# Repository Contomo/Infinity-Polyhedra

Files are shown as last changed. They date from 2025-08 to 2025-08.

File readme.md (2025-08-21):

# Infinity Polyhedra

This repository contains the files, notes, and software related to building an infinity dodecahedron. The project is built around an STM32F401 microcontroller and a custom Python desktop application. While designed for a dodecahedron, the core logic is intended to be flexible enough for other polyhedral geometries.

> *This is a personal project and a work-in-progress.*

<p align="center">
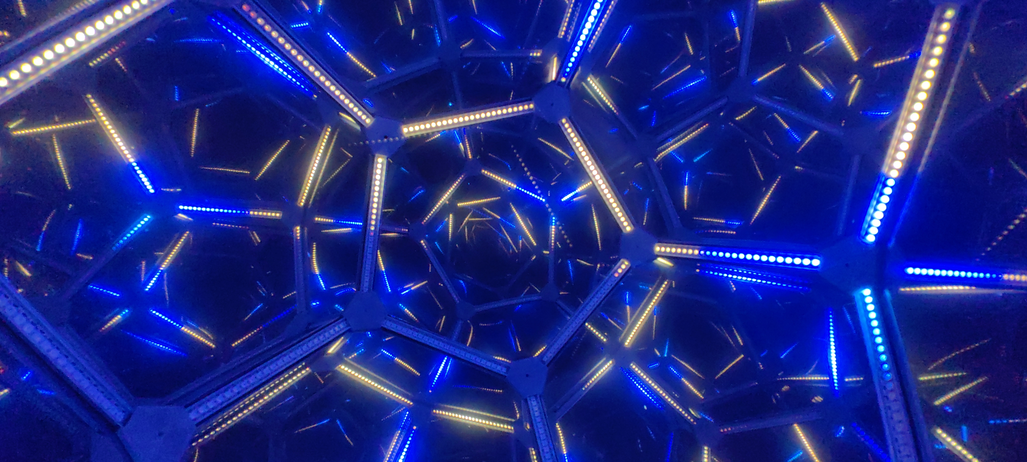
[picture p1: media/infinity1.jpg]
abyss
  
</p>

> [!NOTE]
> This is a complex project that requires some familiarity with Python and STM32CubeIDE. Unless you are simply replicating the build process with the same components, this will likely not be a "download and run" solution.

## Table of Contents

*   [Features](#features)
*   [Hardware](#hardware)
*   [Software](#software)
*   [Design Files](#design-files)
*   [Technical Notes & How It Works](#technical-notes--how-it-works)

## Features

*   **High-Framerate Animations:** The firmware uses a multi-SPI DMA approach to drive a large number of LEDs smoothly, achieving highframe rates.
*   **Geometry-Aware Logic:** The firmware includes a geometric core that can, in theory, be adapted for various polyhedra.
*   **Interactive Edge Remapping:** The app provides a debug mode for remapping physical LED strips to their correct logical edges on the 3D model. This allows for 'vibe wirering'.
*   **PS4 Controller Interface:** The desktop app is built around the use of a PS4 controller, which is the primary method for sending commands to the microcontroller to switch animation modes and operate the remapping interface.

## Hardware

This section covers the physical build of the dodecahedron, including the electronics, materials, and construction notes from my experience.

![PLACEHOLDER: Photo of the fully assembled and lit dodecahedron]

### Electronics

*   **Microcontroller:** STM32F401.
*   **LED Strips:** WS2812B-style addressable LEDs. High-density strips (e.g., 144/m) are recommended. *(1515 300/m are of course better if your pockets allow it)*
*   **Power:** `TODO: HOW MANY PIXIES`

`TODO: Wirering, .4mm enameled and regular corner wired`

### Frame and Panels

*   **Frame:** The dodecahedron frame is built from LED extrusions. (15mm x 10mm)
*   **Panels:** 4mm acrylic panels. i recommend some 3mm foam tape to light seal the edges.
*   **Mirror Film:** The infinity effect is created with one-way mirror foil. The cheapest foil from AliExpress was surprisingly effective, but higher quality film is recommended.
    > **Note on Brightness:** The LEDs can be overwhelmingly bright. Consider using a mirror film/tint 90%+ (e.g., stacking two layers of 80% film) to trade in brightness for reflections.

### Stand

The stand is built from fairly regular aluminum extrusions. (15mm x 15mm) and assembled with some 3D printed parts and M4 black oxide button head screws.  
The files include a small box which gets hooked onto it containing the powersupply and black pill.

## Software

The software is split into two main components: the Python desktop application for control and the C firmware for the STM32 microcontroller.

### Desktop Application (Python)

A PyQt5 application that provides a 3D visualization of the polyhedron for debugging and serves as the primary command interface while sorting the edges and testing animations.

`TODO screenshot`

#### Setup & Running the App

1.  **Controller:** A PS4 controller is not required but highly recommended for interaction. *(with that i recommend [DS4Windows](https://ds4-windows.com/))* Altho any controller would work, or just a keyboard.
2. `TODO: link to serial driver STM32 USB thingy`
3.  **Setup (Windows):** `start_app.bat` to automatically create venv with all necessary dependencies from `requirements.txt`.

The stm32 should automatically connect via serial, and so should your controller with pygame.

### Firmware (STM32)

Provided is a STM32CubeIDE project meant for the STM32F401CCU that drives 720 WS2812B LEDs spread across 3 SPI busses with DMA

Key parameters can be tuned in `config.h`.

## Design Files

inside of the models folder there currently is the full step model, and the old joints as a future design refrence.

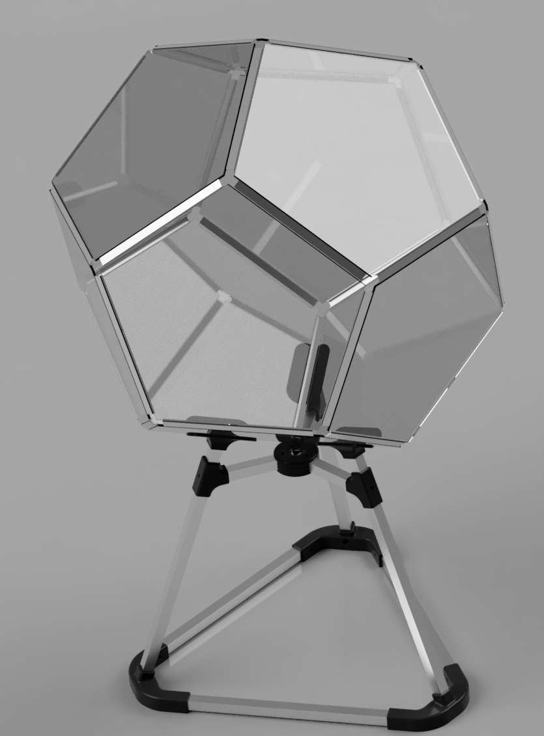
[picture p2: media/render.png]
render


> **Note:** i lost the CAD files of the connector pieces, you shouldnt use them anyways, they are bad. i got them working with a heated insert in the bottom and a single screw, but if i had to do it again i would make sure that the leds lay inside, ie the importance of a contious light strip is greater than the best viewport.

### Technical Notes

The `polyhedron.c` file in the firmware includes functions for basic geometric operations like truncation... A rhombitruncated icosidodecahedron is technically possible to generate but not with the current way we are creating/handling them. For more complex shapes, it would be better to use an external library or mesh program to generate the vertex data and hardcode it. (or help make the poly creation more compliant)

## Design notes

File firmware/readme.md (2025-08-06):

# firmware

## File Structure

```raw
Core/             → STM32Cube HAL init (main.c, dma.c... etc i hope you know the drill)
led/              → render pipeline, mapping, animation, debug
polyhedron/       → geometric model + coordinate transforms
usb/              → CDC serial interface
config.h          → master tuning switches/flags
```

## Debugging

Enable logging in `config.h`:

```c
#define LED_DEBUG_RENDER
#define LED_DEBUG_ANIM
#define LED_DEBUG_MAPPING
```

You’ll get frame timing, animation duration, and heap usage stats over serial.

## Mapping

Custom remapping of virtual edge IDs to physical layout is done with:

```c
static const uint8_t USER_MAP[30] = { … };
static const bool USER_FLIP[30] = { … };
```

Currently theres no way to really save it at runtime yet, i just... recompiled and uploaded.  
*sort -> dump to console -> copy paste to file*

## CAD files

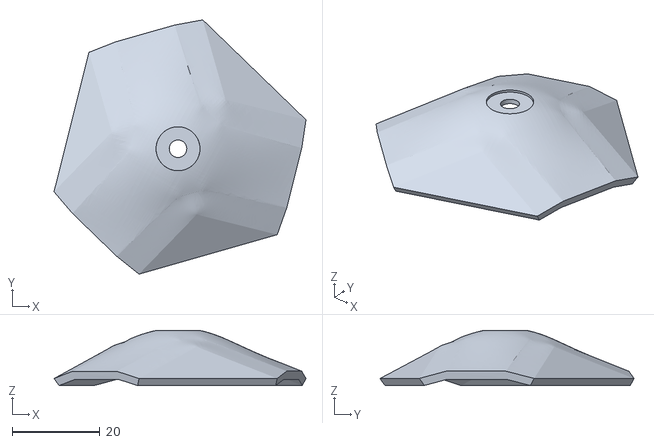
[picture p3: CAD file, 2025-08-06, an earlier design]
model/top_old.stl
57.3 x 57.8 x 12.5

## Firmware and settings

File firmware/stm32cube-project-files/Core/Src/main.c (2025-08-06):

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
/* Includes ------------------------------------------------------------------*/
#include "main.h"
#include "crc.h"
#include "dma.h"
#include "spi.h"
#include "usb_device.h"
#include "gpio.h"

/* USER CODE BEGIN Includes */
/* --------------------------------------------------------------------------
 * main.c – init sequence for polyhedron, mapping and LED renderer
 * -------------------------------------------------------------------------- */

#include "polyhedron.h"   /* Polyhedron geometry + helpers              */
#include "led_mapping.h"  /* init_mapping / mapping_build_pixel_map      */
#include "led_render.h"   /* init_render / framebuffer ops               */
#include "led_debug.h"    /* debug_edge_map_save / debug_ui_*            */
#include "usb_comms.h"    /* flush_usb_buffer / usb_comms_process        */
#include "spi.h"          /* SPI handle declarations (hspi2, hspi3 …)    */

/* USER CODE END Includes */

/* USER CODE BEGIN PD */

#define USB_INIT_DELAY 1000
#define SERIAL_SEND_RATE 50
#define SERIAL_RECIEVE_RATE 20
#define DEBUG_UI_UPDATE_RATE 1 //1000/60
/* USER CODE END PD */

/* USER CODE BEGIN PM */

Polyhedron poly;  /* our geometry instance */


void enable_DWT(void){

	  // ─── enable CPU cycle‐counter ──────────────────────
	  CoreDebug->DEMCR |= CoreDebug_DEMCR_TRCENA_Msk;   // turn on trace
	  DWT->CYCCNT    = 0;                               // clear counter
	  DWT->CTRL    |= DWT_CTRL_CYCCNTENA_Msk;           // start counting

}


/* USER CODE END PM */


void SystemClock_Config(void);
/* USER CODE BEGIN PFP */

/* --------------------------------------------------------------------------
 * GLOBALS
 * -------------------------------------------------------------------------- */

extern SPI_HandleTypeDef hspi1;                       /* declared in spi.c     */
extern SPI_HandleTypeDef hspi2;                       /* declared in spi.c     */
extern SPI_HandleTypeDef hspi3;                       /* declared in spi.c     */
static SPI_HandleTypeDef *const led_spis[] = { &hspi1, &hspi2, &hspi3 };  /* 3 strips */

/* USER CODE END PFP */

/* USER CODE BEGIN 0 */

/* ---------- helpers -------------------------------------- */
uint32_t last_debug_ui_update_time = 0;
uint32_t last_serial_recieve_time = 0;
uint32_t last_serial_send_time = 0;
uint32_t cur_time = 0;
/* ---------------------------------------------------------- */

/* USER CODE END 0 */

/**
 * @brief  The application entry point.
 * @retval int
 */
int main(void) {

	/* MCU Configuration--------------------------------------------------------*/

	/* Reset of all peripherals, Initializes the Flash interface and the Systick. */
	HAL_Init();

	/* Configure the system clock */
	SystemClock_Config();

	/* USER CODE BEGIN SysInit */
	//HAL_Delay(USB_INIT_DELAY);
	/* USER CODE END SysInit */

	/* Initialize all configured peripherals */
	MX_GPIO_Init();
	MX_DMA_Init();
	MX_SPI1_Init();
	MX_SPI2_Init();
	MX_SPI3_Init();
	MX_USB_DEVICE_Init();
	MX_CRC_Init();
	/* USER CODE BEGIN 2 */

	enable_DWT();

	g_global_brightness = 100; /* default global dimming       */

	/* 1. Build the base geometry (regular dodecahedron) */

	poly_init_dodecahedron(&poly);
	/* orient it to stand on the tip */
	poly_orient_to_vertex(&poly, 0);


	/* 2. Build logical-to-physical edge mapping */
    if (!init_mapping(&poly, USER_MAP, USER_FLIP, EDGE_CNT)) { Error_Handler(); }

	/* 3. Initialise LED renderer (framebuffer + SPI DMA buffers) */
	const uint8_t strip_cnt = sizeof led_spis / sizeof led_spis[0];
	if (!init_render(mapping_get_total_pixels(), strip_cnt, led_spis)) { Error_Handler(); }

	/* USER CODE END 2 */

	/* Infinite loop */
	/* USER CODE BEGIN WHILE */
	while (1) {

		if (cur_time - last_serial_send_time > SERIAL_SEND_RATE) {
			last_serial_send_time = cur_time;
			flush_usb_buffer();
		}
		if (cur_time - last_serial_recieve_time > SERIAL_RECIEVE_RATE) {
			last_serial_recieve_time = cur_time;
			usb_comms_process();
		}
		if (cur_time - last_debug_ui_update_time > DEBUG_UI_UPDATE_RATE) {
			last_debug_ui_update_time = cur_time;
			debug_ui_tick();
		}

		g_global_brightness = 100;

		/* USER CODE END WHILE */

		/* USER CODE BEGIN 3 */
		cur_time = HAL_GetTick();
	}
	/* USER CODE END 3 */
}

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


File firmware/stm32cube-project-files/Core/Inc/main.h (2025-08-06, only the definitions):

#define PC13_Pin GPIO_PIN_13
#define PC13_GPIO_Port GPIOC
#define D__Pin GPIO_PIN_11
#define D__GPIO_Port GPIOA
#define D_A12_Pin GPIO_PIN_12
#define D_A12_GPIO_Port GPIOA

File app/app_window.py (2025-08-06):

import sys
import logging
from PyQt5.QtWidgets import (
    QApplication, QMainWindow, QWidget, QSplitter, QMessageBox,
    QVBoxLayout, QLabel, QLineEdit, QPlainTextEdit, QPushButton, QHBoxLayout
)
from PyQt5.QtCore import Qt, QTimer
from PyQt5.QtGui import QColor, QPalette
from matplotlib.backends.backend_qt5agg import FigureCanvasQTAgg as FigureCanvas
from matplotlib.figure import Figure

import config

from controller_core import ControllerCore
import serial_manager
import numpy as np
from debug_viewer import Viewer, _parse


class QtConsoleHandler(logging.Handler):
    def __init__(self, console_widget):
        super().__init__()
        self.console = console_widget
        self.setFormatter(logging.Formatter('%(message)s'))

    def emit(self, record):
        msg = self.format(record)
        self.console.appendPlainText(msg)


class AppWindow(QMainWindow):
    def __init__(self):
        super().__init__()
        self.setWindowTitle("Poly Debug")
        self.resize(1200, 800)

        # Set gray theme
        theme_color = QColor(53, 53, 53)
        theme_recessed_color = QColor(23, 23, 23)
        text_color = QColor(220, 220, 220)

        pal = self.palette()
        pal.setColor(QPalette.Window, theme_color)
        pal.setColor(QPalette.Base, theme_color)
        pal.setColor(QPalette.Text, text_color)
        self.setPalette(pal)

        # Core for serial + input
        logging.info("[info] Starting ControllerCore...")
        self.core = ControllerCore()

        # Build UI
        main_splitter = QSplitter(Qt.Horizontal)
        main_splitter.setStretchFactor(0, 1)
        main_splitter.setStretchFactor(1, 2)

        # Left vertical splitter: controls, sent, received  
        left_splitter = QSplitter(Qt.Vertical)  
        left_splitter.setChildrenCollapsible(False)
        left_splitter.setHandleWidth(4)


        # ─── Autoscroll controls at top ─────────────────────  
        ctrl_widget = QWidget()  
        ctrl_widget.setPalette(pal)  
        hbox = QHBoxLayout(ctrl_widget)  
        hbox.setContentsMargins(10,8,5,5); hbox.setSpacing(5)  
        lbl_auto = QLabel("Autoscroll:")  
        lbl_auto.setStyleSheet("color: #ddd;")  
        hbox.addWidget(lbl_auto)  

        self.autoscroll_sent = True  
        btn_sent = QPushButton("TX"); btn_sent.setCheckable(True); btn_sent.setChecked(True); btn_sent.setFixedSize(40,20)
        btn_sent.setStyleSheet('QPushButton {background-color: #1a1a1a; color: #eee;}')
        btn_sent.clicked.connect(lambda v: setattr(self, 'autoscroll_sent', v))  
        hbox.addWidget(btn_sent)  

        self.autoscroll_recv = True  
        btn_recv = QPushButton("RX"); btn_recv.setCheckable(True); btn_recv.setChecked(True); btn_recv.setFixedSize(40,20)  
        btn_recv.setStyleSheet('QPushButton {background-color: #1a1a1a; color: #eee;}')
        btn_recv.clicked.connect(lambda v: setattr(self, 'autoscroll_recv', v))  
        hbox.addWidget(btn_recv)  
        hbox.addStretch(1)  
        

        # ─── Gyro‐stream toggle ─────────────────────────────
        self.btn_gyro = QPushButton("Gyro Off")
        self.btn_gyro.setCheckable(True)
        self.btn_gyro.setFixedSize(60, 20)
        hbox.addWidget(self.btn_gyro)

        # QTimer to fire at config.GYRO_SEND_RATE Hz
        self.gyro_timer = QTimer(self)
        self.gyro_timer.setInterval(int(1000 / config.GYRO_SEND_RATE))
        self.gyro_timer.timeout.connect(self._send_gyro)
        self.btn_gyro.toggled.connect(self.on_gyro_toggled)




        ctrl_widget.setFixedHeight(30)
        left_splitter.addWidget(ctrl_widget) 

        # ───────────────────────────────────────────────────  
        # 1) Sent & log console – define it first
        self.sent_console = QPlainTextEdit()
        self.sent_console.setReadOnly(True)
        self.sent_console.setStyleSheet("background-color: #1a1a1a; color: #eee;")

        # 2) Composite: Sent console + Input line
        comp_widget = QWidget()
        comp_widget.setPalette(pal)
        comp_layout = QVBoxLayout(comp_widget)
        comp_layout.setContentsMargins(5, 0, 0, 5)
        comp_layout.setSpacing(2)

        # Sent console
        comp_layout.addWidget(self.sent_console)

        # Input line (fixed height)
        self.input_line = QLineEdit()
        self.input_line.setPlaceholderText("Type help for help...")
        self.input_line.setFixedHeight(24)
        self.input_line.setStyleSheet("background-color: #1a1a1a; color: #eee;")
        self.input_line.returnPressed.connect(self._on_enter)
        # add input line to composite layout
        comp_layout.addWidget(self.input_line)

        
        # wrap the composite widget and add to splitter
        left_splitter.addWidget(comp_widget)

        # 3) Received console (2/3)
        self.recv_console = QPlainTextEdit()
        self.recv_console.setReadOnly(True)
        self.recv_console.setStyleSheet("background-color: #1a1a1a; color: #eee;")
        # wrap in a widget for consistent margins/border
        recv_widget = QWidget()
        recv_widget.setPalette(pal)
        recv_layout = QVBoxLayout(recv_widget)
        recv_layout.setContentsMargins(5, 5, 5, 5)
        recv_layout.setSpacing(2)
        recv_layout.addWidget(self.recv_console)
        left_splitter.addWidget(recv_widget)


        # Plot area
        canvas_widget = QWidget()
        canvas_widget.setPalette(pal)
        canvas_layout = QVBoxLayout(canvas_widget)
        self.figure = Figure(facecolor='#353535')
        self.canvas = FigureCanvas(self.figure)
        self.canvas.toolbar_visible = False
        canvas_layout.addWidget(self.canvas)

        main_splitter.addWidget(left_splitter)
        main_splitter.addWidget(canvas_widget)
        self.setCentralWidget(main_splitter)




        # ─── Metrics display (rolling averages) ─────────────────────────────────
        # how many samples to average over
        self.metrics_history = config.METRICS_HISTORY
        self.frame_times = []
        self.anim_times = []

        # build a little bar above the autoscroll controls
        metrics_widget = QWidget()
        metrics_layout = QHBoxLayout(metrics_widget)
        metrics_layout.setContentsMargins(10, 5, 5, 0)
        metrics_layout.setSpacing(15)

        self.lbl_frame_time = QLabel("Avg frame: – ms")
        self.lbl_frame_time.setStyleSheet("color: #ddd;")
        metrics_layout.addWidget(self.lbl_frame_time)

        self.lbl_anim_time = QLabel("Avg anim: – ms")
        self.lbl_anim_time.setStyleSheet("color: #ddd;")
        metrics_layout.addWidget(self.lbl_anim_time)

        metrics_layout.addStretch(1)
        metrics_widget.setFixedHeight(25)

        # insert above the existing ctrl_widget (which is at index 0)
        left_splitter.insertWidget(0, metrics_widget)
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

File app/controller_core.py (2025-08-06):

#!/usr/bin/env python3
"""
controller_core.py – zentrale Logik für Joystick/Keyboard und Serial I/O
"""
import time
import logging
import pygame
import config
import serial_manager

class ControllerCore:
    """
    Core logic for joystick and keyboard input, serial reconnect/drain,
    sending commands based on mappings.
    """
    def __init__(self):
        logging.info("[info] Initializing ControllerCore...")
        pygame.init()
        pygame.joystick.init()
        self._gyro = None   # placeholder for last‐read gyro tuple
        # Liste aller verbundenen Joysticks
        self.joysticks = []
        self._init_joysticks()

        # Button-Debounce-/Repeat-State
        self.btn_last = {btn: 0.0 for btn in config.JOYSTICK_BUTTON_MAPPING}
        self.btn_repeat = {btn: False for btn in config.JOYSTICK_BUTTON_MAPPING}

        # Zeit für nächstes Axis-Kommando
        self.next_axis_time = 0.0

        logging.info("[info] ControllerCore initialized.")

    def _init_joysticks(self):
        """Initial scan: alle aktuell eingesteckten Joysticks verbinden"""
        count = pygame.joystick.get_count()
        for idx in range(count):
            try:
                joy = pygame.joystick.Joystick(idx)
                joy.init()
                self.joysticks.append(joy)
                jid = getattr(joy, 'get_instance_id', joy.get_id)()
                logging.info(f"[info] Joystick '{joy.get_name()}' connected (instance {jid})")
            except Exception as e:
                logging.error(f"[error] Failed to init joystick {idx}: {e}")

    def step(self):
        now = time.time()

        # Serielle Verbindung: reconnect & drain
        serial_manager.try_reconnect()
        serial_manager.drain()

        # Pygame Event-Handling
        try:
            pygame.event.pump()
            events = pygame.event.get()
        except Exception as e:
            logging.error(f"Pygame event pump/get failed: {e}")
            events = []

        for event in events:
            if event.type == pygame.JOYDEVICEADDED:
                idx = event.device_index
                try:
                    joy = pygame.joystick.Joystick(idx)
                    joy.init()
                    self.joysticks.append(joy)
                    jid = getattr(joy, 'get_instance_id', joy.get_id)()
                    logging.info(f"[info] Joystick '{joy.get_name()}' connected (instance {jid})")
                except Exception as e:
                    logging.error(f"[error] Could not add joystick at index {idx}: {e}")
            elif event.type == pygame.JOYDEVICEREMOVED:
                inst = getattr(event, 'instance_id', None)
                for joy in list(self.joysticks):
                    jid = getattr(joy, 'get_instance_id', joy.get_id)()
                    if jid == inst:
                        logging.info(f"[info] Joystick '{joy.get_name()}' disconnected (instance {jid})")
                        self.joysticks.remove(joy)
                        break

        try: 
            for joy in self.joysticks:
                for btn, cmd in config.JOYSTICK_BUTTON_MAPPING.items():
                    try:
                        pressed = joy.get_button(btn)
                    except Exception:
                        continue
                    if pressed:
                        delay = config.REPEAT_DELAY if self.btn_repeat[btn] else config.DEBOUNCE_MS
                        if now - self.btn_last[btn] >= delay:
                            serial_manager.send(cmd)
                            self.btn_last[btn] = now
                            self.btn_repeat[btn] = True
                    else:
                        self.btn_repeat[btn] = False

            # Polling der Achsen für kontinuierliche Befehle
            for joy in self.joysticks:
                for cmd, axis in config.AXIS_MAPPING.items():
                    try:
                        val = joy.get_axis(axis)
                    except Exception:
                        continue
                    if abs(val) > config.STICK_DEADZONE and now >= self.next_axis_time:
                        delta = val * (config.STICK_SENSE / config.UPDATES_PER_SEC)
                        serial_manager.send(f"{cmd} {delta:+.3f}")
                        self.next_axis_time = now + 1.0 / config.UPDATES_PER_SEC

            for cmd, axis_list in config.TRIGGER_MAPPING.items():
                for axis, sign in axis_list:
                    val = joy.get_axis(axis)
                    if val > config.TRIGGER_DEADZONE/2 and now >= self.next_axis_time:
                        delta = sign * val * (config.TRIGGER_SENSE / config.UPDATES_PER_SEC)
                        serial_manager.send(f"{cmd} {delta:+.3f}")
                        self.next_axis_time = now + 1.0 / config.UPDATES_PER_SEC 

        except: 
            pass

                # ─── if the UI asked for gyro, sample & send it ─────────────────
        if self.joysticks:
            try:
                self._gyro = None
            except:
                pass

    def get_gyro(self):
        """
        Return the latest gyro reading as (x,y,z), or None if unavailable.
        Implement gyro sampling in your main loop to populate self._gyro.
        """
        return self._gyro
    
    def shutdown(self):
        logging.info("[info] Shutting down ControllerCore...")
        serial_manager.close_serial()
        pygame.quit()

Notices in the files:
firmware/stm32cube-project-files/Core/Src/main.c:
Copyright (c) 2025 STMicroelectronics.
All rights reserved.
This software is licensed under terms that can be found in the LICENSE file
